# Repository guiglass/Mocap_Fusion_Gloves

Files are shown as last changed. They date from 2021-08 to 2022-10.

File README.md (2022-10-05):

# Mocap_Fusion_Gloves
Arduino/SteamVR motion capture gloves. Check out more of my free motion capture tools and apps at www.MocapFusion.com
<br>
## Assembly Guide:
Youtube Tutorial (https://www.youtube.com/watch?v=PCBvUHJH8Gw)
<br>
Files for assembling and programming these super low latency "DIY" motion capture glove using an Arduino and 5x SEN-08606 Flex Sensor 4.5" for each finger and a Vive tracker that is strapped to the 3D printed hand strap.
<br>
<br>
Parts:
<br>
nRF24 wireless radio (RP-SMA): https://www.sparkfun.com/products/705

nRF24 wireless radio: https://www.sparkfun.com/products/691

SEN-08606 Flex Sensor: https://www.sparkfun.com/products/8606

Knit Gloves: https://www.amazon.com/OPT-Brand-Winter-Gloves-Wholesale/dp/B07XZL1ZK8

Dynaflex (black): https://www.amazon.com/18280-DYNAFLEX-Black-Building-Material/dp/B000BQWXEO

Boneduino with nRF24 raido: http://duinopeak.com/index.php?route=product/product&manufacturer_id=9&product_id=30

<br>
<br>
Wiring Diagrams:
<br>

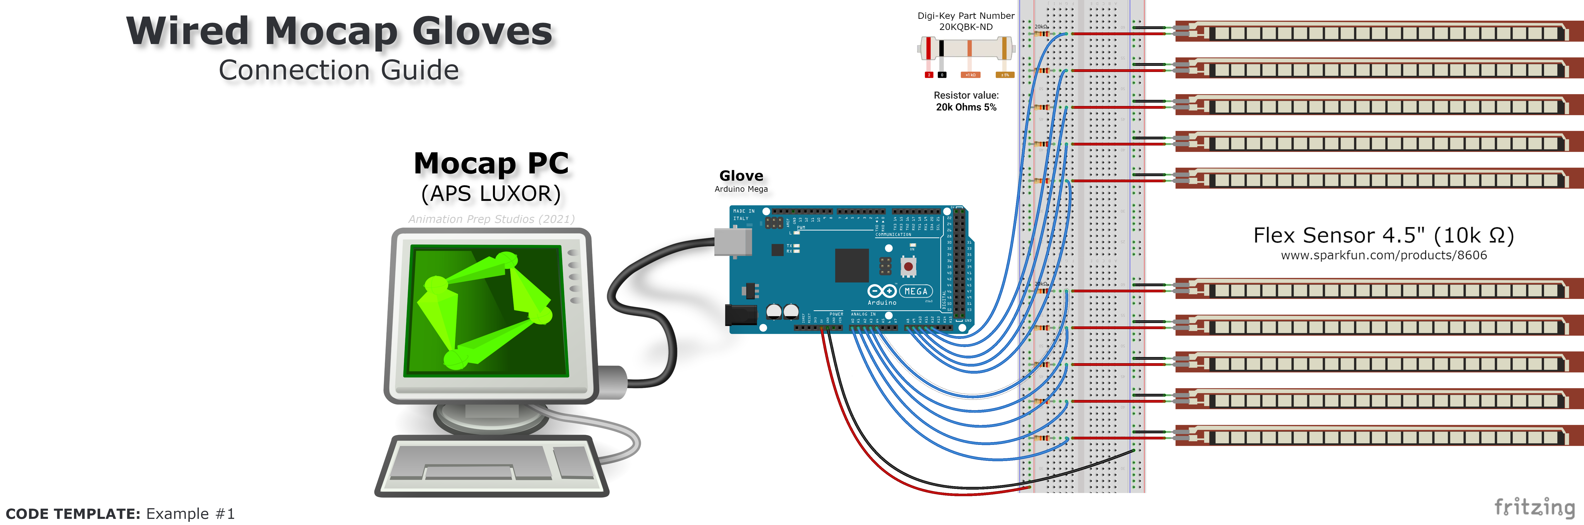
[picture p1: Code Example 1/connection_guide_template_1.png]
Code Example 1

Example #1 requires only a single Arduino Mega and is wired directly to the mocap PC through USB.

***
<br>

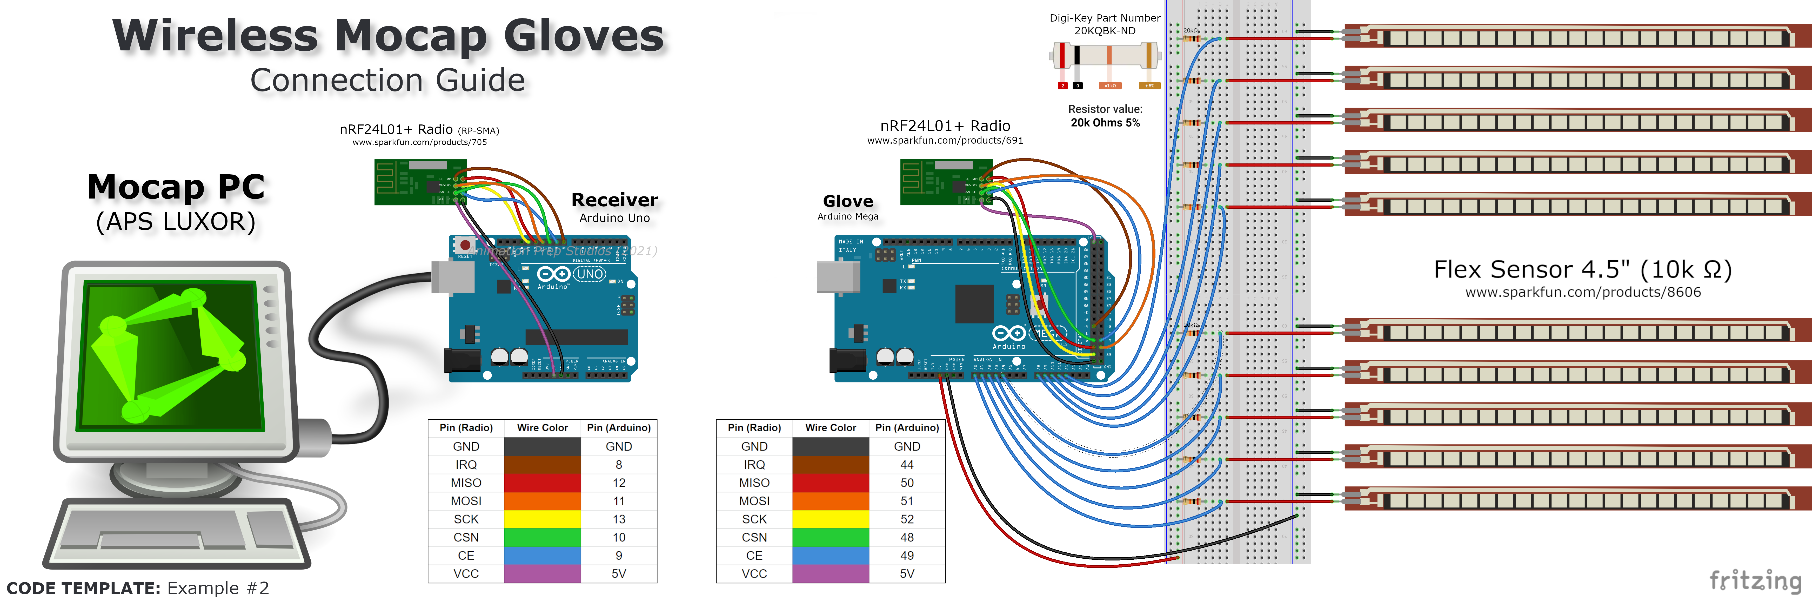
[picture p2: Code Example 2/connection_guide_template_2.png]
Code Example 1

Example #2 Uses a Arduino Mega for for the gloves and sends the finger data wirelessly to a receiving Arduion Uno connected to the mocap PC through USB.

***
<br>

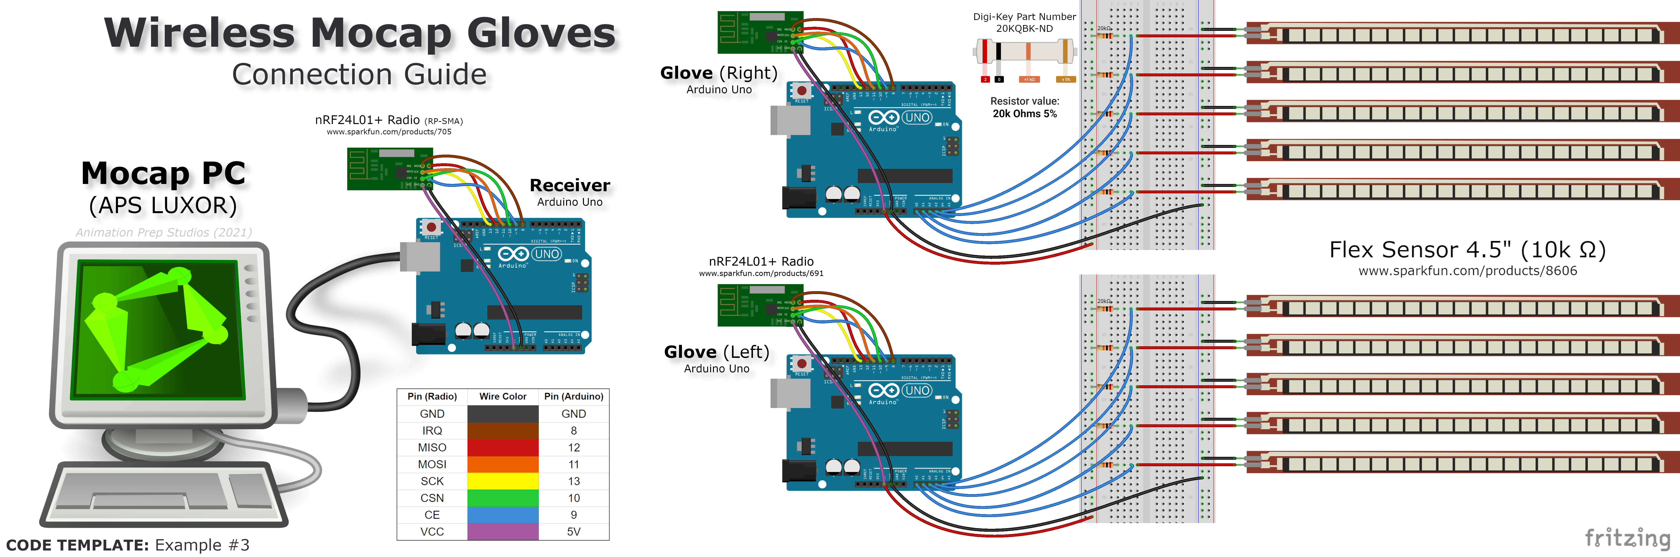
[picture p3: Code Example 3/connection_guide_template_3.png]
Code Example 1

Example #3 two Arduino Unos or Boneduinos connected to each glove individually, both send the finger data wirelessly to a receiving Arduino Uno connected to the mocap PC through USB.

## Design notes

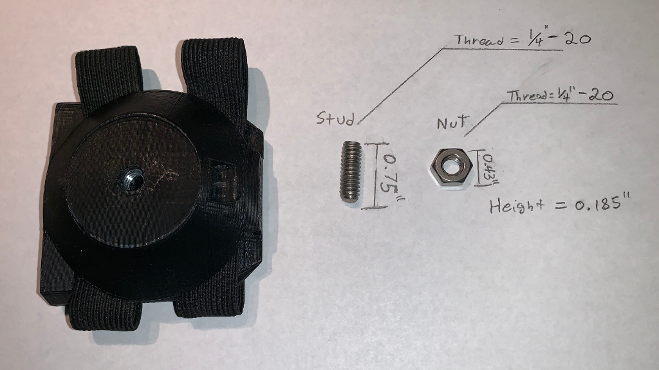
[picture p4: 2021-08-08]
3D Printer/hardware.png

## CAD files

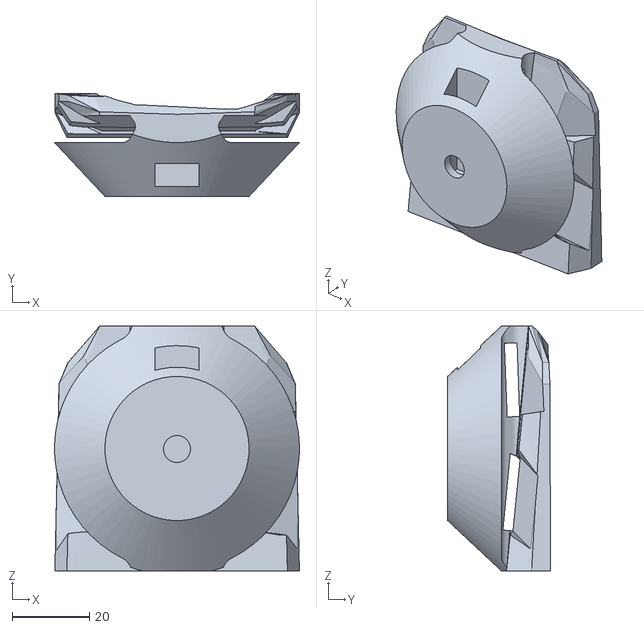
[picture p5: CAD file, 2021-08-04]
3D Printer/HandTrackerHolder_Left.stl
63.6 x 26.7 x 63.6

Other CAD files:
3D Printer/MoCapGlove_Right.stl
3D Printer/HandTrackerHolder.blend

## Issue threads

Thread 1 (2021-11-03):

some questions about the gloves

visonpon, 2021-11-03:
Hi, thanks for sharing this wonderful and amazing work. I have followed your DIY tutorial and made the gloves work. but I have some questions hope you can help.

First, can I export the hand track results in blender format or can you share the idea or code on how to transform the sensor's value to controll the fingers?

Second, the gloves can not track the movements like fingers detach horizontally, do you have a plan to slove it?

Third, hope there are documents on how to use the LUXOR in details.

Thanks
sincerely.

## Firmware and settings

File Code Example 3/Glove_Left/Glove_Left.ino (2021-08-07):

/*
 * Copyright 2021 Animation Prep Studios - All rights reserved.
 * If you use this code in production or other products you must give attribution to Animation Prep Studios.
 * 
 * This example shows simple wireless communication using a Arduino Uno with nRF24+ radio that sends data to a Arduino Uno with nRF24+ attached to a PC running Animation Prep Studio - Mocap Fusion (LUXOR).
 * Each analog input reads the bend value of a SEN-08606 Flex Sensors (4.5" typical).
 */
 
#include <SPI.h>
#include <nRF24L01.h>
#include <RF24.h>

#define CE_PIN  9
#define CSN_PIN 10

const byte thisSlaveAddress[5] = {'R','x','A','A','A'}; //LEFT HAND ADDRESS

RF24 radio(CE_PIN, CSN_PIN);

char dataReceived[10]; // this must match dataToSend in the TX
char ackData[] = {0, 0, 0, 0, 0, 0, 0, 0};
bool newData = false;

//==============

void setup() {

/*  
    //ARDUINO UNO
    pinMode(A0, INPUT);
    pinMode(A1, INPUT);
    pinMode(A2, INPUT);
    pinMode(A3, INPUT);  
    pinMode(A4, INPUT);
*/
    //BONEDUINO    
    pinMode(A0, INPUT);
    pinMode(A1, INPUT);
    pinMode(A2, INPUT);
    pinMode(A3, INPUT);  
    pinMode(A6, INPUT);
        
    radio.begin();
    radio.setDataRate( RF24_1MBPS );
    radio.setPALevel(RF24_PA_HIGH);
    
    radio.openReadingPipe(1, thisSlaveAddress);

    radio.enableAckPayload();
    radio.writeAckPayload(1, &ackData, sizeof(ackData)); // pre-load data

    radio.startListening();
}

//==========

void loop() {
    getData();
}

//============

void getData() {
    if ( radio.available() ) {
        radio.read( &dataReceived, sizeof(dataReceived) );
        updateReplyData();
        newData = true;
    }
}
//================

void updateReplyData() {
    //For Boneduino must write all pins low

/*
    //ARDUINO UNO
    int _A0 = analogRead(A0);  
    int _A1 = analogRead(A1);  
    int _A2 = analogRead(A2);  
    int _A3 = analogRead(A3);
    int _A4 = analogRead(A4);
*/
    //BONEDUINO    
    int _A0 = analogRead(A0);  
    int _A1 = analogRead(A1);  
    int _A2 = analogRead(A2);  
    int _A3 = analogRead(A3);
    int _A4 = analogRead(A6);
    
    ackData[0] = _A0 & 0b0000000011111111;
    ackData[1] = ((_A0 & 0b0000111100000000) >> 8) + ((_A1 & 0b0000000000001111) << 4);
    ackData[2] = ((_A1 & 0b0000111111110000) >> 4);
    ackData[3] = _A2 & 0b0000000011111111;
    ackData[4] = ((_A2 & 0b0000111100000000) >> 8) + ((_A3 & 0b0000000000001111) << 4);
    ackData[5] = ((_A3 & 0b0000111111110000) >> 4);
    ackData[6] = _A4 & 0b0000000011111111;
    ackData[7] = ((_A4 & 0b0000111100000000) >> 8) ;

    radio.writeAckPayload(1, &ackData, sizeof(ackData)); // load the payload for the next time
}

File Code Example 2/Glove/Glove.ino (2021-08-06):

/*
 * The LUXOR Mocap Gloves wireless example demonstrates communication with an nRF24+ radio on a receiving Arduion coneected to a PC running AnimationPrepStudio.
 * Each analog input reads the bend value of a SEN-08606 Flex Sensors (4.5" typical).
 */


#include <SPI.h>
#include <nRF24L01.h>
#include <RF24.h>

#define CE_PIN  49
#define CSN_PIN 48

const byte thisSlaveAddress[5] = {'R','x','A','A','A'}; //WIRELESS ADDRESS

RF24 radio(CE_PIN, CSN_PIN);

char dataReceived[10]; // this must match dataToSend in the TX
char data[] = {0, 0, 0, 0, 0, 0, 0, 0, 0, 0, 0, 0, 0, 0, 0, 0};
bool newData = false;

//==============

void setup() {
    //LEFT HAND
    pinMode(A0, INPUT);
    pinMode(A1, INPUT);
    pinMode(A2, INPUT);
    pinMode(A3, INPUT);  
    pinMode(A4, INPUT);

    //RIGHT HAND
    pinMode(A8, INPUT);
    pinMode(A9, INPUT);
    pinMode(A10, INPUT);
    pinMode(A11, INPUT);  
    pinMode(A12, INPUT);
    
    radio.begin();
    radio.setDataRate( RF24_1MBPS );
    radio.setPALevel(RF24_PA_HIGH);
    
    radio.openReadingPipe(1, thisSlaveAddress);

    radio.enableAckPayload();
    radio.writeAckPayload(1, &data, sizeof(data)); // pre-load data

    radio.startListening();
}

//==========

void loop() {
    getData();
}

//============

void getData() {
    if ( radio.available() ) {
        radio.read( &dataReceived, sizeof(dataReceived) );
        updateReplyData();
        newData = true;
    }
}

//================

void updateReplyData() {

    //Now do the 
    int _A0 = analogRead(A0);  
    int _A1 = analogRead(A1);  
    int _A2 = analogRead(A2);  
    int _A3 = analogRead(A3);
    int _A4 = analogRead(A4);  
    data[0] = _A0 & 0b0000000011111111;
    data[1] = ((_A0 & 0b0000111100000000) >> 8) + ((_A1 & 0b0000000000001111) << 4);
    data[2] = ((_A1 & 0b0000111111110000) >> 4);
    data[3] = _A2 & 0b0000000011111111;
    data[4] = ((_A2 & 0b0000111100000000) >> 8) + ((_A3 & 0b0000000000001111) << 4);
    data[5] = ((_A3 & 0b0000111111110000) >> 4);
    data[6] = _A4 & 0b0000000011111111;
    data[7] = ((_A4 & 0b0000111100000000) >> 8) ;

    //Now do the RIGHT HAND
    int _B0 = analogRead(A8);  
    int _B1 = analogRead(A9);  
    int _B2 = analogRead(A10);  
    int _B3 = analogRead(A11);
    int _B4 = analogRead(A12);  
    data[8] = _B0 & 0b0000000011111111;
    data[9] = ((_B0 & 0b0000111100000000) >> 8) + ((_B1 & 0b0000000000001111) << 4);
    data[10] = ((_B1 & 0b0000111111110000) >> 4);
    data[11] = _B2 & 0b0000000011111111;
    data[12] = ((_B2 & 0b0000111100000000) >> 8) + ((_B3 & 0b0000000000001111) << 4);
    data[13] = ((_B3 & 0b0000111111110000) >> 4);
    data[14] = _B4 & 0b0000000011111111;
    data[15] = ((_B4 & 0b0000111100000000) >> 8) ;

    radio.writeAckPayload(1, &data, sizeof(data)); // load the payload for the next time
}

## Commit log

2021-08-06 Updated IO pin addresses
2021-08-07 Changed pin numbers for boneduino compatibility
2021-08-07 Fixed IO pin assignment
    [Glove_Left.ino]
